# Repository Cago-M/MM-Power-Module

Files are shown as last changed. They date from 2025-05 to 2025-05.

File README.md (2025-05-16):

# MM-Power-Module

This repository contains the complete design files, documentation, and output artifacts of the Power Subsystem used in a micro-mouse robot. It includes USB-C power negotiation, multi-rail regulation, Li-ion battery support, and load switching for motors and auxiliary peripherals

#### Repository Contents
| Folder/File | Description |
| --- | --- |
| `kicad_project/` | Full KiCad 8+ project files (`.kicad_sch`, `.kicad_pcb`, symbols, footprints). |
| `gerber/` | Gerber files for PCB manufacturing (RS-274X standa. |
| `bom/` | Bill of Materials in `.csv` and `.xlsx` formats. |
| `csv_exports/` | CSV exports of netlist, components, positions for assembly. |
| `images/` | High-res renderings of the board (3D view, top view, bottom view). |
| `README.md` | You're reading it. |

## Subsystem Overview
The power subsystem fulfills the following requirements:
- Provide 5V and 3V3 regulated rails to sensors, MCU, and logic.
- Interface with USB-C input and negotiate 9V via CH224K.
- Support auxiliary laods via two TPS22929D load switches.
- Power four DC motors via DRV8833 motor drivers.

#### Key Components
| Component | Function |
| --- | --- |
| CH224K | USB-C PD negotiation (9 V out) |
| LM296T-5 | 5 V linear regulator |
| AMS1117-3.3 | 3.3 V LDO regulator |
| TP4056 | Li-ion charger (w/ protection) |
| DRV8833 | Dual H-bridge motor drivers |
| TPS22929D | Load switches for aux peripherals |
| INA219 | Current sensing (I²C telemetry) |

#### Board Previews

## License
This project is released under the MIT License. Attribution is appreciated if reused or modified.

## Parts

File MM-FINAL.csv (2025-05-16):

Reference | Qty | Value | DNP | Exclude from BOM | Exclude from Board | Footprint | Datasheet
C1,C5,C6,C9 | 4 | 1u |  |  |  | Capacitor_SMD:C_0603_1608Metric | ~
C2 | 1 | 100u |  |  |  | Capacitor_SMD:C_0402_1005Metric | ~
C3,C7 | 2 | C_Small (0.1uF) |  |  |  | Capacitor_SMD:C_0402_1005Metric | ~
C4 | 1 | 220u |  |  |  | Capacitor_SMD:C_0402_1005Metric | ~
C11,C13 | 2 | 0.1u |  |  |  | Capacitor_SMD:C_0603_1608Metric | ~
C12,C14 | 2 | 10u |  |  |  | Capacitor_Tantalum_SMD:CP_EIA-3216-18_Kemet-A | ~
C16,C20 | 2 | 10u |  |  |  | Capacitor_SMD:C_0402_1005Metric | ~
C17,C18 | 2 | C_Polarized |  |  |  | Capacitor_SMD:C_0402_1005Metric | ~
C19 | 1 | 47u |  |  |  | Capacitor_SMD:C_0402_1005Metric | ~
D1,D2 | 2 | LED |  |  |  | LED_SMD:LED_0402_1005Metric | ~
D3 | 1 | 1N5822 |  |  |  | Diode_THT:D_DO-201AD_P15.24mm_Horizontal | http://www.vishay.com/docs/88526/1n5820.pdf
D4 | 1 | D_Zener |  |  |  | Diode_SMD:D_0402_1005Metric | ~
J1 | 1 | Conn_02x16_Odd_Even |  |  |  | Connector_PinHeader_2.54mm:PinHeader_2x16_P2.54mm_Vertical | ~
J2 | 1 | USB4085-GF-A_REVB |  |  |  | footprints:GCT_USB4085-GF-A_REVB
J3 | 1 | Conn_01x02 |  |  |  | Connector_JST:JST_XH_B2B-XH-A_1x02_P2.50mm_Vertical | ~
JP_9V1,JP_9V_PWR1,JP_EXT_1,JP_EXT_2,JP_M1,JP_M2 | 6 | Conn_01x02 |  |  |  | Connector_PinHeader_2.54mm:PinHeader_1x02_P2.54mm_Vertical | ~
L1 | 1 | 100u |  |  |  | Inductor_THT:L_Axial_L5.3mm_D2.2mm_P2.54mm_Vertical_Vishay_IM-1 | ~
L2 | 1 | 33u |  |  |  | Inductor_SMD:L_01005_0402Metric | ~
Q3 | 1 | AO3401A |  |  |  | Package_TO_SOT_SMD:SOT-23 | http://www.aosmd.com/pdfs/datasheet/AO3401A.pdf
R1 | 1 | 6.8k |  |  |  | Resistor_THT:R_Axial_DIN0204_L3.6mm_D1.6mm_P7.62mm_Horizontal | ~
R3,R4 | 2 | 1k |  |  |  | Resistor_THT:R_Axial_DIN0204_L3.6mm_D1.6mm_P1.90mm_Vertical | ~
R5,R6,R7,R8,R11,R13,R14 | 7 | 10k |  |  |  | Resistor_THT:R_Axial_DIN0204_L3.6mm_D1.6mm_P1.90mm_Vertical | ~
R9 | 1 | 5k |  |  |  | Resistor_THT:R_Axial_DIN0204_L3.6mm_D1.6mm_P1.90mm_Vertical | ~
R10 | 1 | 1.67k |  |  |  | Resistor_THT:R_Axial_DIN0204_L3.6mm_D1.6mm_P1.90mm_Vertical | ~
R12 | 1 | 0.1 |  |  |  | Resistor_THT:R_Axial_DIN0204_L3.6mm_D1.6mm_P1.90mm_Vertical | ~
SW4,SW5 | 2 | SS-12D10G5 |  |  |  | footprints:SS-12D10G5_XKB | https://jlcpcb.com/api/file/downloadByFileSystemAccessId/8589837903817187328
U1,U2 | 2 | DRV8833PWP |  |  |  | footprints:IC_DRV8833PWP | http://www.ti.com/lit/ds/symlink/drv8833.pdf
U3 | 1 | CH224K |  |  |  | Package_SO:SSOP-10-1EP_3.9x4.9mm_P1mm_EP2.1x3.3mm | https://www.wch.cn/downloads/file/301.html
U4,U5 | 2 | TPS22929D |  |  |  | Package_TO_SOT_SMD:SOT-23-6 | http://www.ti.com/lit/ds/symlink/tps22929d.pdf
U6 | 1 | TP4056-42-ESOP8 |  |  |  | Package_SO:SOIC-8-1EP_3.9x4.9mm_P1.27mm_EP2.41x3.3mm_ThermalVias | https://www.lcsc.com/datasheet/lcsc_datasheet_2410121619_TOPPOWER-Nanjing-Extension-Microelectronics-TP4056-42-ESOP8_C16581.pdf
U7,U10 | 2 | LM2596T-5 |  |  |  | Package_TO_SOT_THT:TO-220-5_P3.4x3.7mm_StaggerOdd_Lead3.8mm_Vertical | http://www.ti.com/lit/ds/symlink/lm2596.pdf
U9 | 1 | INA219AxDCN |  |  |  | Package_TO_SOT_SMD:SOT-23-8 | http://www.ti.com/lit/ds/symlink/ina219.pdf
U11 | 1 | AMS1117-3.3 |  |  |  | Package_TO_SOT_SMD:SOT-223-3_TabPin2 | http://www.advanced-monolithic.com/pdf/ds1117.pdf

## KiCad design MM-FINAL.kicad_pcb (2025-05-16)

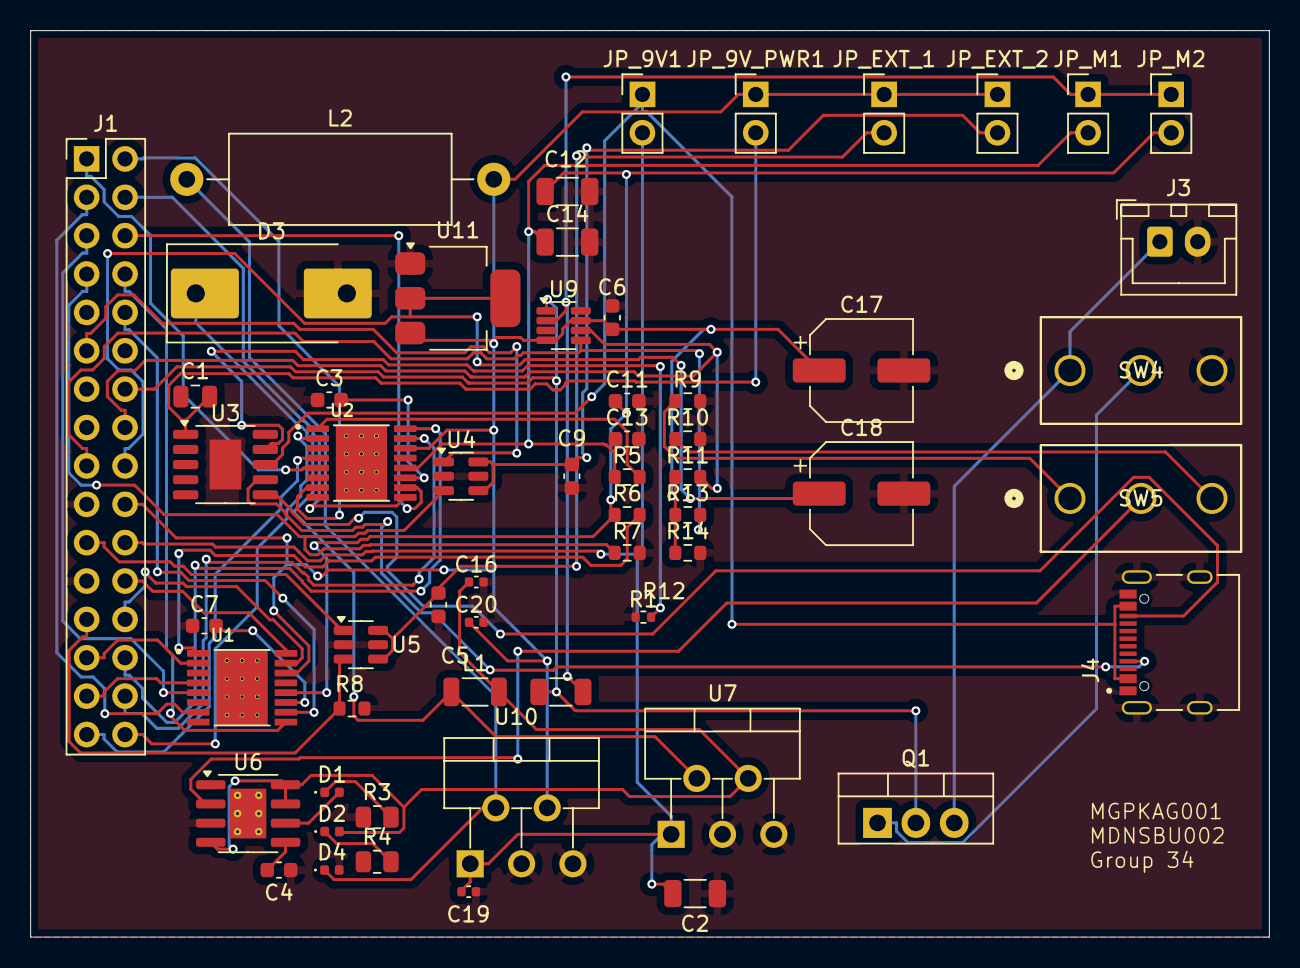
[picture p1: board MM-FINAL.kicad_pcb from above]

Board: 2 copper layers, 82.0 x 60.0 mm, 58 parts (0 on the bottom side), 53 nets.

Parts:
C1: 1u; C_0805_2012Metric
C2: 100u; C_1206_3216Metric
C3, C7: C_Small (0.1uF); C_0603_1608Metric
C4: 220u; C_0603_1608Metric
C5, C6, C9: 1u; C_0603_1608Metric
C11, C13: 0.1u; C_0603_1608Metric
C12, C14: 10u; C_1206_3216Metric
C16, C20: 10u; C_0402_1005Metric
C17, C18: 10u; CP_Elec_6.3x5.4
C19: 47u; C_0402_1005Metric
D1, D2: LED; LED_0402_1005Metric
D3: 1N5822; D_SMC-RM10_Universal_Handsoldering
D4: D_Zener; D_0402_1005Metric
J1: Conn_02x16_Odd_Even; PinHeader_2x16_P2.54mm_Vertical
J3: Conn_01x02; JST_XH_B2B-XH-A_1x02_P2.50mm_Vertical
J4: TYPE-C-31-M-12; HRO_TYPE-C-31-M-12
JP_9V1, JP_9V_PWR1: Conn_01x02; PinHeader_1x02_P2.54mm_Vertical
JP_EXT_1, JP_EXT_2: Conn_01x02; PinHeader_1x02_P2.54mm_Vertical
JP_M1, JP_M2: Conn_01x02; PinHeader_1x02_P2.54mm_Vertical
L1: 100u; L_1206_3216Metric
L2: 40u; L_Axial_L14.5mm_D5.8mm_P20.32mm_Horizontal_Fastron_HBCC
Q1: IRF9540N; TO-220-3_Vertical
R1: 6.8k; R_0402_1005Metric
R3, R4: 1k; R_0805_2012Metric
R5, R6, R7, R8, R11, R13, R14: 10k; R_0603_1608Metric
R9: 5k; R_0603_1608Metric
R10: 1.67k; R_0603_1608Metric
R12: 0.1; R_1206_3216Metric
SW4, SW5: SS-12D10G5; SS-12D10G5_XKB
U1, U2: DRV8833PWP; IC_DRV8833PWP
U3: CH224K; SSOP-10-1EP_3.9x4.9mm_P1mm_EP2.1x3.3mm
U4, U5: TPS22929D; SOT-23-6
U6: TP4056-42-ESOP8; SOIC-8-1EP_3.9x4.9mm_P1.27mm_EP2.41x3.3mm_ThermalVias
U7, U10: LM2596T-5; TO-220-5_P3.4x3.7mm_StaggerOdd_Lead3.8mm_Vertical
U9: INA219AxDCN; SOT-23-8
U11: AMS1117-3.3; SOT-223-3_TabPin2

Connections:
3V3 Out: C18.1, J1.18, U11.2 (VO)
5V Out: C6.2, C17.1, C20.1, J1.20, JP_9V_PWR1.1, JP_EXT_1.1, JP_EXT_2.1, L2.2, R11.1, R13.1, R14.1, U1.14 (VINT), U2.14 (VINT), U9.4 (VS), U9.7 (A0), U10.4 (FB), U11.3 (VI)
+BATT: J1.14, Q1.2 (D), R12.1, U9.1 (IN+)
+BATT_out: JP_M1.1, JP_M2.1, R12.2, U9.2 (IN-)
CTRL_EXT_LOAD1: J1.25, R8.1, U5.3 (ON)
CTRL_EXT_LOAD2: J1.7, R7.1, U4.3 (ON)
EXT_LOAD1_OUT: J1.21, U5.1 (VOUT)
EXT_LOAD2_OUT: J1.11, U4.1 (VOUT)
GND: C1.1, C2.2, C3.1, C4.2, C5.2, C6.1, C7.1, C9.2, C11.2, C12.2, C13.2, C14.2, C16.2, C17.2, C18.2, C19.2, C20.2, D3.2 (A), D4.2 (A), J1.19, J1.23, J3.2, J4.A1_B12 (GND), J4.B1_A12 (GND), J4.S1 (SHIELD), J4.S2 (SHIELD), J4.S3 (SHIELD), J4.S4 (SHIELD), R1.1, R3.1, R4.1, R7.2, R8.2, R9.2, R10.2, R14.2, SW4.3 (C), U1.3 (AISEN), U1.6 (BISEN), U1.13 (GND), U1.17 (GND), U2.3 (AISEN), U2.6 (BISEN), U2.13 (GND), U2.17 (GND), U3.11 (GND), U4.2 (GND), U4.5 (GND), U5.2 (GND), U5.5 (GND), U6.1 (TEMP), U6.3 (GND), U7.3 (GND), U7.5 (~ON/OFF), U9.3 (GND), U9.8 (A1), U10.3 (GND), U10.5 (~ON/OFF), U11.1 (GND)
High Voltage (9V): C2.1, C19.1, J1.22, JP_9V1.2, U7.1 (VIN), U10.1 (VIN)
I2C1_SCL: J1.16, R11.2, U9.6 (SDA)
I2C1_SDA: J1.17, R13.2, U9.5 (SCL)
LiPo +ve: C4.1, U6.5 (BAT)
MOTOR1_A_OUT: J1.32, U2.2 (AOUT1)
MOTOR1_B_OUT: J1.31, U2.4 (AOUT2)
MOTOR2_A_OUT: J1.2, U2.7 (BOUT1)
MOTOR2_B_OUT: J1.1, U2.5 (BOUT2)
MOTOR2_CTRL1: J1.4, U2.9 (BIN1)
MOTOR2_CTRL2: J1.6, U2.10 (BIN2)
MOTOR3_A_OUT: J1.27, U1.2 (AOUT1)
MOTOR3_B_OUT: J1.29, U1.4 (AOUT2)
MOTOR3_CTRL1: J1.24, U1.16 (AIN1)
MOTOR3_CTRL2: J1.26, U1.15 (AIN2)
MOTOR4_CTRL1: J1.8, U1.9 (BIN1)
MOTOR4_CTRL2: J1.10, U1.10 (BIN2)
Motor1_CTRL1: J1.28, U2.16 (AIN1)
Motor1_CTRL2: J1.30, U2.15 (AIN2)
Motor4_A_OUT: J1.3, U1.7 (BOUT1)
Motor4_B_OUT: J1.5, U1.5 (BOUT2)
unnamed: D1.2 (A), U6.6 (~STDBY)
unnamed: D1.1 (K), R3.2
unnamed: C16.1, D2.2 (A), L1.2, U6.4 (V_{CC}), U6.7 (~CHRG), U6.8 (CE), U7.4 (FB)
unnamed: D2.1 (K), R4.2
unnamed: D3.1 (K), L1.1, U7.2 (OUT)
unnamed: D4.1 (K), L2.1, U10.2 (OUT)
unnamed: J4.A5 (CC1), U3.7 (CC1)
unnamed: J4.B5 (CC2), U3.6 (CC2)
unnamed: J4.A4_B9 (VBUS), J4.B4_A9 (VBUS), JP_9V1.1, U3.8 (VBUS)
unnamed: C1.2, JP_9V_PWR1.2, U3.1 (VDD)
unnamed: C5.1, JP_EXT_1.2, U5.4 (VIN), U5.6 (VIN)
unnamed: C9.1, JP_EXT_2.2, U4.4 (VIN), U4.6 (VIN)
unnamed: C13.1, C14.1, JP_M1.2, R5.1, U2.12 (VM)
unnamed: C11.1, C12.1, JP_M2.2, R6.1, U1.12 (VM)
unnamed: Q1.1 (G), SW4.2 (B)
unnamed: R9.1, SW5.1 (A)
unnamed: SW5.2 (B), U6.2 (PROG)
unnamed: R10.1, SW5.3 (C)
unnamed: C7.2, U1.11 (VCP)
unnamed: R6.2, U1.1 (~SLEEP)
unnamed: C3.2, U2.11 (VCP)
unnamed: R5.2, U2.1 (~SLEEP)
unnamed: R1.2, U3.9 (CFG1)
VBAT+: J3.1, Q1.3 (S), SW4.1 (A)
